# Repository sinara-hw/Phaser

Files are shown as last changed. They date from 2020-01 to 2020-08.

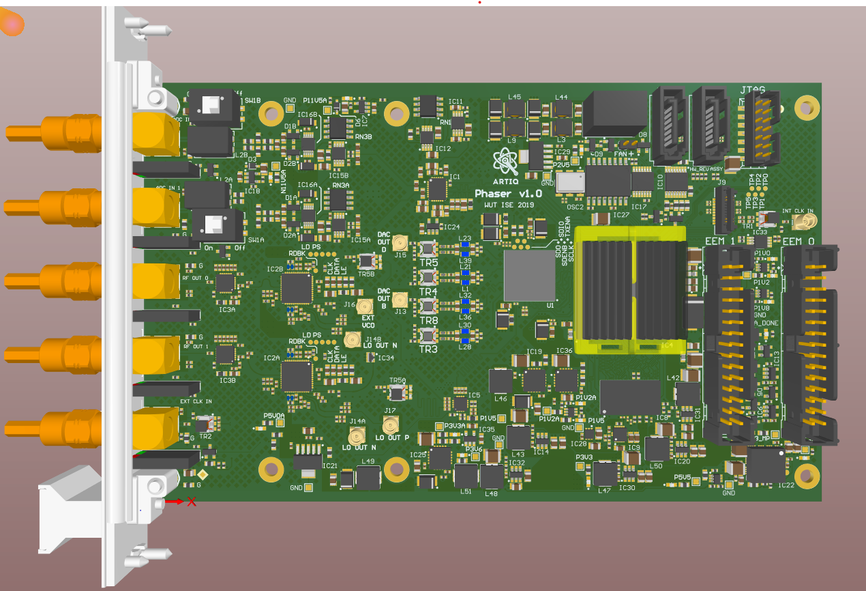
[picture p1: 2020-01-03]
DOC/Phaser-top.png

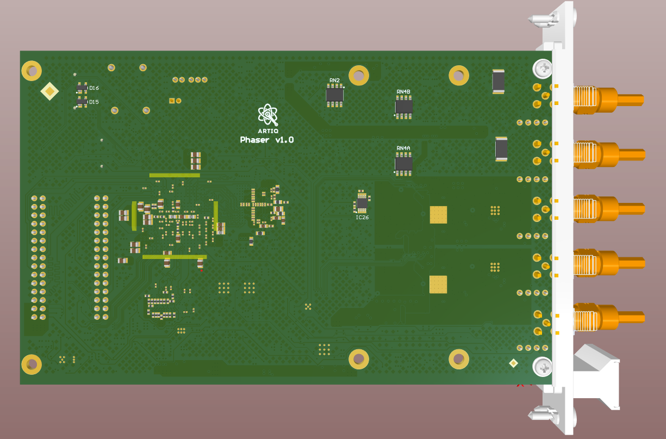
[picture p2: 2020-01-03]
DOC/Phaser-bot.png

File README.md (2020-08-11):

# Phaser
Quad channel 1GS/s RF generator card with dual IQ upconverter and dual 5MS/s ADC and FPGA in EEM form factor

## Design Files

Design files (schematics, PCB layouts, BOMs) can be found at [Phaser/Releases](https://github.com/sinara-hw/Phaser/releases).

## Wiki

More information can be found on the [wiki](https://github.com/sinara-hw/Phaser/wiki).

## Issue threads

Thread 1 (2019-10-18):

design sketch

hartytp, 2019-10-18:
2 channel ADC + DAC board

Hardware design sketch, needs fleshing out...

Digital:
- 2 EEM connectors
- TBD FPGA (probably small/medium Artix 7)
- Same RAM as Kasli
- Maybe a SATA or two
- Possibly, but probably not, Si5324 for DRTIO (would need to check power budget carefully to make sure this feasible)

Analog Input:
- Same as Sampler except
- Go for the 5MSPS ADC in the same family
- Increase AFE pole frequencies to ~1MHz to give more bandwidth

DAC:
- TBD DACs
- Two AFE population variants

Baseband AFE:
- Only using DAC I output, Ignore (terminate?) DAC Q outputs
- same AFE as Urukul
- Probably drop the pre-amps to keep the power dissipation down (in any case, with Booster we have gain to spare)
- Optionally drop the switches too

Upconversion AFE:
- ADL5375 IQ mixer (I and Q channels)
- same AFE as baseband mode, but different (no?) filter and magnetics

Clocking:
- 125MHz from SMA/MMCX/on-board XO
- HMC830 DAC clock PLL (copy loop filter from Sayma)
- HMC830 LO clock PLL (copy loop filter from Sayma)
- Decent LVDS clock fanout buffer

gkasprow, 2019-10-19:
Will we use 2x LTC2000 DAC then mixer and a single output?
Or two dual DACs and two mixers?

What about making the design 3-channel. Two baseband channels and one with upconversion? In this way switching from one mode to another won't require that many changes.

gkasprow, 2019-10-19:
do you want USB JTAG or we can use solution from Banker that Kasli can upgrade config FLASH via I2C ?

hartytp, 2019-10-19:
>Will we use 2x LTC2000 DAC then mixer and a single output?

The DAC will most likely be http://www.ti.com/lit/ds/symlink/dac34sh84.pdf

This has two IQ pairs. So, the idea is we either use only the Is and drop the Qs (baseband) or use an external IQ mixer depending on the desired output frequency range.

> What about making the design 3-channel. Two baseband channels and one with upconversion? In this way switching from one mode to another won't require that many changes.

We can't make three channels work in terms of thermal/power management, (front panel) space, EEM link bandwidth.

The proposal would be to just have a population option to select (basically, just a solder jumper to bypass the mixer). If that turns out to be hard to do, we can scrap the upconversion *the key element of this design is baseband performance, upconversion is an optional extra*.

hartytp, 2019-10-19:
> do you want USB JTAG or we can use solution from Banker that Kasli can upgrade config FLASH via I2C ?

I'll leave all those kinds of decisions to @jordens

jordens, 2019-10-20:
Some more background info on the design, DAC choice evaluation, DSP requirements etc:
https://paper.dropbox.com/doc/Phaser--AnD485kbUiDhEmmZ0cv8NUlZAg-yC4c4GTJ4hbA969VxIL9K

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

@gkasprow A way to talk to the flash via I2C would be really nice. But on Banker/Humpback this is really slow (a bitstream flashing operation takes some 5-10 minutes) and I think the I2C-SPI converter is the bottleneck (the way it limits and buffers each transaction). Maybe there is a simple way to speed it up or maybe we can figure out a different way to get this done over I2C.

@hartytp Didn't we say we'd use the DAC PLL to go from 125 MHz to 1 GHz DAC CLK? I didn't factor in the need to set up a HMC830 to clock the DAC.

hartytp, 2019-10-20:
> Also I'm not sure the Si5324 would be strictly needed for DRTIO. For the downlink it's not needed and for the uplink it may well not be required. And if there's a clock from MMCX/SMA then it's not needed for that either. I'd really try to minimize the clocking complexity for this.

Agreed, I don't want an Si5324.

hartytp, 2019-10-20:
> @hartytp Didn't we say we'd use the DAC PLL to go from 125 MHz to 1 GHz DAC CLK? I didn't factor in the need to set up a HMC830 to clock the DAC.

True, I'd forgotten about the internal DAC clock PLL. At one point we definitely discussed having 2 HMC830s, but it's very possible we agreed to scrap one later on and I forgot. Since we can steal the register set for the HMC830 from Sayma, I assume the additional work required to support a HMC830 for the DAC clock is basically just the usual work associated with hooking up an extra SPI bus?

In any case: (a) for the initial contract, the internal DAC PLL is definitely fine (b) I agree that we should try to minimise complexity/power consumption/cost as far as possible and should try to avoid using an HMC830 for the DAC clock (in any case, that's typically ~10-20dB less important than the mixer LO due to the frequency difference).

The things I would potentially be worried about with the internal DAC PLL would be noise and phase determinism (e.g. due to VCO auto cal). The latter may be solvable by using an active loop filter, fiddling with registers. I'll have a look at the data sheets/noise models and have a think. I'll open a separate issue on this.

jordens, 2019-10-20:
Iirc the DAC pll doesn't do any auto calibration. We'd set the vco range and be done. And I don't see how that would be affected by an active LF.
The DAC setup is pretty simple. We could freeze that and wouldn't have to implement some passthrough mechanism. The hmc830 does complicate things. it's pretty different.

jordens, 2019-10-20:
And the DAC34**H**84 would be sufficient. No S needed.

hartytp, 2019-10-20:
> Iirc the DAC pll doesn't do any auto calibration.

It may not; I haven't looked at the data sheet yet (just listing things that could be issues). AFAICT it's generally only the really high-performance ones that narrow-band step-tuned VCOs.

> And I don't see how that would be affected by an active LF.

Well, the question is why a step-tuned VCO would affect the output phase at all but empirically, it does! My understanding is that (a) the different bands on the same VCO can alter the leakage (b) the different bands change the DC bias voltage required to achieve a given output frequency, which (due to finite DC LF gain) requires a different DC offset at the phase detector. Putting an integrator between the PFD and VCO basically eliminates both effects.

The other thing I might worry about would be the PFD frequency for the DAC internal PLL (again, affects noise and drift). The 830 is nice as it can run directly at 125MHz. If there were any limitations that required us to run the DAC PFD at lower frequencies then I might be worried. but, again, this isn't something I've thought about yet, just a note to self for things to consider before finalising the design.

gkasprow, 2019-10-20:
Here is a very initial sketch. Just to estimate IO resources, power, clocking, etc.
[Phaser_SCH.PDF](https://github.com/sinara-hw/Phaser/files/3748520/Phaser_SCH.PDF)

jordens, 2019-10-21:
@hartytp Leakage and finite DC gain are the same thing in the loop filter. If there is no leakage, the DC gain is infinite and vice versa.
There is just one VCO and we need to do the coarse tuning (band select) ourselves in any case. The DAC provides a measurement of the LF voltage for that.
But sure, you can kill that effect with another integrator. I would suspect though that if PVT are sufficiently unstable to require an active LF to kill leakage-induced phase noise, you will typically also run out of the VCO fine tuning range because of PVT. And then the active LF is pointless.

jordens, 2019-10-21:
For IQ mixer, also check the [TRF3705](http://www.ti.com/lit/ds/symlink/trf3705.pdf). Better linearity, more output power, less noise, lower low-f corner, less bias, lower input power, more gain, but more power consumption, and lower high-f corner.

hartytp, 2019-10-24:
@gkasprow I looked over the design sketch. Looks good! I think the issues we've opened cover the main things. This time, let's try to finish the schematic review before doing work on the layout to avoid wasting time.

I'd like to send Stabilizer and Fastino to manufacture before beginning work on this in earnest. But maybe we can get to that some time next week? Depends on @jordens review timeline.

jordens, 2019-10-25:
I have already reviewed fastino and stabilizer as much as I'm involved. I'm not blocking those.
On phaser I can do some review next week. Between the issues and notes already filed and the design sketch there isn't much to be done.
Fpga wise an artix in that large pin compatible range from the a50t downwards will be fine (same as on sayma rtm).

hartytp, 2019-11-01:
@gkasprow I'm really keen to complete my initial design review soon. Could you have a go at producing a schematic only (no layout) RC please?

hartytp, 2019-11-05:
@gkasprow ping...what do you think the timeline for getting a schematic RC is? I'm itching to get this one off to manufacture and into my lab :)

gkasprow, 2019-11-06:
I plan to finish them until Friday.

hartytp, 2019-11-06:
🎆

Closed 2019-11-06.

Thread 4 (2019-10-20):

DAC LPF

gkasprow, 2019-10-20:
I assume we need some LPF filter between DAC and the mixer. The LPF needs to be fully differential. We can go for this [one](https://www.minicircuits.com/WebStore/dashboard.html?model=DLFCG-540%2B), but there are not many options with different frequencies.

jordens, 2019-10-21:
Or just a discrete one, like for the AD9148. Maybe not even such an aggressive 5th order. Yes, needs to be differential.
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

hartytp, 2019-10-21:
@gkasprow the MCL filter isn't the right approach IMHO. It only comes in a small range of values, none of which are what we'd ideally want (with 1GHz clock and 540MHz, you don't get much filtering for some of the lower frequencies we'll use).

I suspect that a well-designed discrete filter with tight-tolerance components will be the way to go

hartytp, 2019-10-21:
@gkasprow how important is it to use a differential filter instead of, say, two single-ended filters?

gkasprow, 2019-10-21:
The differential filter has usually better matching between negative and positive terminals. Moreover, depending on the construction, it may attenuate mainly differential components while two filters will attenuate both diff and common-mode components. Some differential filters are two single-ended ones in one package. So there is no simple answer to the question.
I don't think it is that important in our case.

hartytp, 2019-10-21:
@gkasprow do you know of any other sources of any other manufacturers of SMT RF differential filters. I didn't see any at a look (but I might have missed one).

For the upconversion, I guess we'd really want a double differential filter for the I and Q channels to maintain amplitude and phase balance. So, it's not so clear to me that 4xsingle-ended is really worse than 2xdifferential.

Unless you're worried about this, I suggest we just go for standard MCL single-ended filters. I'd expect that the matching between filters will be better than the matching between discrete filters.

gkasprow, 2019-10-21:
I'm not sure if lTCC would have tighter tolerance than a classical filter composed of 1% LC components.
They don't even specify the tolerance in DS.

hartytp, 2019-10-21:
Ok. Are you happy designing a discrete differential LPF for this then? Since it needs to work to 1GHz, we'll have to be careful to simulate the parasitics correctly to get something that performs as expected.

jordens, 2019-10-22:
I would also go for discrete. Third or fifth order like in the data-sheets and eval boards.

gkasprow, 2019-10-23:
I will simply copy the eval board layout.

gkasprow, 2019-11-06:
I plan to use this filter
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

hartytp, 2019-11-06:
Cool!

Questions:
- the dac/modulator there aren’t the ones we’re using. Does that matter (different parasitics)
- will you use the same BOM lines as the eval board to keep the parasitic the same?
- how much will the layout affect the response?
- do you have a curve of the filter response? If not, can we do a quick sim with all component models
- are you using components with very tight tolerances (eg the i and q channels need really good matching to preserver the mixers excellent side and suppression)

gkasprow, 2019-11-06:
I'm using 2% inductors and capacitors in the 0603 packages to make modifications easier. I will remove the lower layers of PCB to limit the parasitics. We are talking about 2 components 68nH and 2.7pF. In the case of the capacitor, the influence of its parasitic capacitance is critical and I'm not sure if we can precisely simulate such a circuit. EVKIT does not have any filter.
The DACs have current outputs that are loaded with 50R. It's hard to say if its parasitics matter that much.

gkasprow, 2019-11-06:
Anyway, I will estimate pads capacitances and do the simulation.

gkasprow, 2019-11-07:
The very first approach
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
and the charasteristics:
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

gkasprow, 2019-11-07:
This schematic includes all parasitic components
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

jordens, 2019-11-07:
ok. @hartytp I think this is probably worse than 0.1 dB flatness over 20 MHz already at 300 MHz.

hartytp, 2019-11-07:
> ok. @hartytp I think this is probably worse than 0.1 dB flatness over 20 MHz already at 300 MHz.

Indeed. 0.1dB is better than we need (just 1dB is a bit on the high side, but nought-dot-a-few-dB is ok).

hartytp, 2019-11-07:
Thanks greg, that looks pretty good. What are the inductor part numbers?

gkasprow, 2019-11-07:
Coilcraft 0603HP-68NXGLU

Closed 2019-11-07.

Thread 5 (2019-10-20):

Mixer bypass

gkasprow, 2019-10-20:
do we need a switchable mixer bypass?

hartytp, 2019-10-21:
No. Far too much effort to put in RF switches. Let's just make it a population option.

jordens, 2019-10-21:
Yes. Just 0R/capacitor jumpers.
It might make sense to maintain the baseband (no mixer) configuration as a different variant since the difference in population (PLL, fanouts, mixers, filters, biasing, new power rails etc) and cost is probably significant.

hartytp, 2019-10-21:
> It might make sense to maintain the baseband (no mixer) configuration as a different variant since the difference in population (PLL, fanouts, mixers, filters, biasing, new power rails etc) and cost is probably significant.

Yes, definitely.

Ideally, I'd also like a FP indicator (text/LED/whatever) to show which population variant one is using.

dtcallcock, 2019-10-28:
Bit late to the Phaser party, but anyway I'm very interested in using it for a new project.  However, I will need to be able to run down as low as 1MHz on the mixer bypass variant.  Is there a low frequency cutoff in the spec anywhere (I couldn't find one)?  If not, can we make 1MHz the spec?

The only issue I see right now is that the 10nF DC-blocks are a bit weedy.  Perhaps they could be 100nF in this variant?

jordens, 2019-10-28:
The balun (TLT vs not) will be the bigger hurdle for low f.

jordens, 2019-10-28:
Well, depends on how we do it. Whether the balun would bypass the mixer and whether the mixer is  unbalanced.

dtcallcock, 2019-10-28:
Yes, it seems that if this is a population variant there is quite a bit of flexibility.  I think I need to see a sketch of where we are right now though as I'm having a hard time picturing it from the comment threads.

hartytp, 2019-10-28:
@dtcallcock that should be possible. The magnetics are the things that are most likely to cause a problem. But I suspect we can find a way of making this work.

gkasprow, 2019-10-28:
@dtcallcock  I assume you want a circuit like in Urukul. We can make the balun assembly option so you could use one that works from 400kHz like [ADT1-1WT+](https://ww2.minicircuits.com/pdfs/ADT1-1WT.pdf). Anyway, this one works up to 800MHz so it should satisfy other applications as well.

hartytp, 2019-10-28:
Yes maybe that for the bb variant and a broadband tlt for the upconverter?

dtcallcock, 2019-10-28:
That works.

jordens, 2019-10-29:
We may get around having to use a transformer for.the upconverter variant.

hartytp, 2019-10-29:
How?

jordens, 2019-10-29:
There's no need for a transformer between mixer and upconv if the bias and matching work out (see data-sheets). And after the mixer it's already single ended.

jordens, 2019-10-29:
But for this application I am pretty sure that mixing down after phaser is actually the easiest approach. Then you can go all the way to DC.

gkasprow, 2019-10-29:
@jordens do you mean to use mixer as a diff to single ended converter with LO switched off ?

jordens, 2019-10-29:
I believe we'd use

* Baseband variant: dac, diff discrete lowpass, balun, digital attenuator, switch. The the balun could be the standard ADT 1-1 or maybe a 4:1 for a bit more power if that works with the matching
* Upconverter variant: dac, diff discrete lowpass, mixer, digital attenuator, switch.

jordens, 2019-10-29:
But yes. If you want to go all the way to DC, I'd use the baseband variant, and slap an external downconverter (125 MHz LO e.g.) after it.

hartytp, 2019-10-29:
@jordens yes, thank you, I'd forgotten that trf372017 has differential I/Q inputs, but single-ended RF output. So, we shouldn't need any balun for the upconversion path, which simplifies things. FWIW since the upconverter has internal DACs for bias control, I'd just AC-couple the DAC outputs in all cases.

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

hartytp, 2019-10-29:
(as you say though, we need to check that matching doesn't require a balun, so need to check data sheets/eval boards before making a decision)

hartytp, 2019-10-29:
> I believe we'd use

Yes, completely agree. We can potentially scrap the switch as well to get some more output power/reduce complexity, but I'm fine keeping it...

NB if we use the DAC amplitude rather than the switch to turn the output on/off then we'll need to rethink the noise eater control logic...

hartytp, 2019-10-29:
> But yes. If you want to go all the way to DC, I'd use the baseband variant, and slap an external downconverter (e.g. 125 MHz LO, Phaser into RF and use IF output) after it. It's not the ultimate solution in terms of low frequency noise but then again for DC applications other issues (like DAC tempco 15-30 ppm/K) might be problematic anyway.

I currently don't see any use-case for DC on this design. Without knowing the use-case, it's hard to comment on suitability, but I generally suspect this is not going to be the right design for dc-sensitive applications. e.g. may be better to use a bias-T to combine Fastino and Phaser outputs or something like that. Anyway, this is outside the scope of this design and a little off-topic.

jordens, 2019-10-29:
Yes. Let's kill the switch as well. If 40ns resolution is fine, then a virtual "TTL" channel to blank the output would be easy.

hartytp, 2019-10-29:
> Yes. Let's kill the switch as well. If 40ns resolution is fine, then a virtual "TTL" channel to blank the output would be easy.

I only imagine using phaser in cases where we need pulse-shaping, so the switch wouldn't be used anywhere in our setup (well, maybe to kill LO leakage during long off periods, but that's a bit niche).

Not sure what the right way of blanking the noise eater is. Maybe we just need to manually enable/disable it at the start/end of each pulse, but that's a separate conversation.

jordens, 2019-10-29:
Or we can just use the TXENA pin which presumably has either data clock resolution (2ns) or dac clock resolution (1ns). This is would be good for noise eating as well.
Unfortunately it affects both channels.

hartytp, 2019-10-29:
> Or we can just use the TXENA pin which presumably has either data clock resolution (2ns) or dac clock resolution (1ns). This is would be good for noise eating as well.
Unfortunately it affects both channels.

Well, worth hooking up the FPGA at least for future use.

jordens, 2019-10-30:
For silencing the output (LO leakage) there's also PWD_TX_DIV in the upconverter accessible through SPI and AFAICT without sideeffects.

gkasprow, 2019-11-06:
I got the mixer devkit. If som measurements are needed, I can make them.

gkasprow, 2019-11-06:
I left the RF switches.

hartytp, 2019-11-07:
Where are they? I don’t think we can have a switch on the I as it will destroy the I/Q matching. Let’s just use solder jumpers

jordens, 2019-11-07:
I think he meant the RF switch after the mixer.

hartytp, 2019-11-07:
@gkasprow either way, let's drop it. Unnecessary insertion loss and complexity and we can quickly turn the DAC off in software so it's not helpful to have a separate switch

gkasprow, 2019-11-07:
I meant this circuit
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
OK, let's get rid of them.

Closed 2019-11-07.

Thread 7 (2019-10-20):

Config FLASH update

gkasprow, 2019-10-20:
> A way to talk to the flash via I2C would be really nice. But on Banker/Humpback this is really slow (a bitstream flashing operation takes some 5-10 minutes) and I think the I2C-SPI converter is the bottleneck (the way it limits and buffers each transaction). Maybe there is a simple way to speed it up or maybe we can figure out a different way to get this done over I2C.

What about making SPI FLASH available on the LVDS lines?
One can achieve it in a few ways:
- add LVDS mux that switches 4 EEM lanes to the FLASH. It is controlled by I2C. Simplest and robust. LVDS muxes like [this ](https://www.maximintegrated.com/en/products/analog/analog-switches-multiplexers/MAX14979E.html) They do not cause additional lane delays.
- make the FLASH inerface inside of the FPGA as it is done for JTAG FLASH programmer. Needs some gateware development and is not fail-safe. One cannot recover in case of broken flash content
- use existing I2C to SPI converter + add  tihgtly coupled, slow LVDS receivers that work only for FLASH writing. I2C to SPI works for status/readout. In this way we avoid switching the LVDS bus but it may cause issues and complicates the things since require both I2C and SPI access.
- make a CPLD  I2C to SPI bridge that utilises fast I2C mode.

jordens, 2019-10-21:
(1) is pretty complex on the coding side and would need quite some development on Kasli and then it's as easy to do (2) instead which doesn't need additional hardware. (3) also requires additional tooling, gateware and scatters some complexity across different interfaces. My impression is that (4) would also require quite some development work for not that much gain and reusability.

I would keep the existing I2C-SPI solution and go for (2) at some later point.
There are good ways to make it (almost completely) fail-safe with multiple bitstreams in flash and warm booting.
And we already have two decent, robust solutions (JTAG cable and I2C-SPI). If we can't implement (2) then they are good enough for me. Waiting 10 minutes for a firmware update is not that dramatic at the user end. Developing with JTAG connected is a must in any case since flashing is still about 2 orders of magnitude slower than loading a bitstream via JTAG. No point in wiring up another FTDI solution here.

gkasprow, 2019-11-06:
done.
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

jordens, 2019-11-07:
Is the FPGA's CFG_CCLK high-Z during INIT_B low? I'm not sure since it's dedicated.

jordens, 2019-11-07:
I believe the answer to the above is yes.

But wouldn't it be useful to connect PROGRAM_B to a I2C-SPI GPIO (and either derive FLASH_UP_EN from INIT_B or to drop the FPGA_DONE input)? INIT_B alone doesn't reload the configuration.

gkasprow, 2019-11-07:
Right. Do we need INIT_B at all?

gkasprow, 2019-11-07:
OK, to hold FPGA configuration one needs to hold init_B low. TO restart configuration one needs to toggle PROGRAM_B. So, what if I connect them both with two Schottky diodes to GPIO?
In this way I will pull them low together.
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

jordens, 2019-11-07:
Schottky sounds good. Just make sure that they can pull low enough against the pullups.

gkasprow, 2019-11-07:
DONE line has 300R pullup so I will add two MOSFETs.
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

Closed 2019-11-07.

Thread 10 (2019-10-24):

choice of upconverter

hartytp, 2019-10-24:
I'd like to aim to use upconverters with inbuilt LO PLLs. The thinking here is that it's highly desirable to have a LO PLL on the EEM, rather than relying on an external LO. Generating the LO with a PLL outside the modulator is mildly tricky because the quadrature hybrids in the upconverter don't like harmonics, which most PLLs produce. Filtering the harmonics is a pain. Easier to let the modulator designer take care of that. Having the PLL inside the LO also makes the two channels fully independent, which may or may not be useful for a given application, and means we only have one clock frequency to distribute (the reference)/saves us a front panel connector.

The potential downsides of using a modulator with inbuild PLL/VCO are:
- power consumption -- but, doing the maths, I don't think having two PLLs/VCOs uses much more power than having an external PLL (at least, for a high-performance one like an HMC830)
- less choice of modulator.

@gkasprow do you know any manufacturers of upconverters with PLLs/VCOs apart from TI and ADI? I'll post a table here with our options soon.

hartytp, 2019-10-24:
PN | BW (GHz) | power (W) | supplier |
---| ---| --- | --- |
[trf372017](http://www.ti.com/lit/ds/symlink/trf372017.pdf) | 0.3-4.8 | ? | TI
[trf3722](http://www.ti.com/lit/ds/symlink/trf3722.pdf) | 0.4 - 4.2 | ? | TI

hartytp, 2019-10-24:
*TRF372017*
- internal bias
- VCO output, route to MMCM/UFL for debugging (can be DNP by default)
- 200mA from 3V3, 117mA from 5V = 1.245W
- f_pfd max: 100MHz (so we will run at 62.5MHz)

VCO at 2GHz, noise normalised to 1GHz

f offset | HMC830 noise (-dBc/Hz) | trf372017 noise(-dBc/Hz)
--- | --- | ---
10k | - | 92
100k | 122 | -
1M | 147 | 139
10M | 168 | 157
50M | 177 | 160

So the VCO is something like 10dB worse than the HMC830, which is fine.

- PLL figure of merit is the normalized phas enoise floor of the PFD in dBc/Hz. i.e. measure in-band phase noise (closed loop) and subtract `20log(N) + 10log(f_pfd)`
- HMC830 is (integer-N) is -230dBc/Hz. So, at 2GHz, f_pfd=62.5MHz that gives
  - N = 32
  - `PN = -230dBc/Hz + 20*log(32) + 10*log(62.5) = -122dBc/Hz`
- For TRF372017 (figure 21)
  - `f_pfd` = 1.6MHz, `f_lo_out = 1GHz` so `N = 625`
  - `FOM = -103 - 20*log(625) - 10*log(1.6e6) = -221`
- So, again, the TRF372017 PFD is about 10dB worse (I can't find a flicker spec for this PN)
- Bearing in mind that the 830 is about the best on the market for PLL with integrated VCO, that's good!

hartytp, 2019-10-24:
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

Worse case variations are of order 0.2dB/60K = 0.07%/K. From the plots, it's generally quite a bit better than that (a lot at certain frequency/temp combinations)

hartytp, 2019-10-24:
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

hartytp, 2019-10-24:
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

hartytp, 2019-10-24:
trf3722
- seems broadly comparable.
- VCO bb noise is a bit better, close in noise a bit worse. PFD FOM is about identical (-221dBc/Hz)

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

hartytp, 2019-10-24:
HMC1197
- 320mA*5V + 48mA*3.3V = 1.75W
- PFD FOM is -230dBc (integer N)
- VCO is pretty close to HMC830

- NB I assume the TI FOMs were integer N, but wasn't specified in data sheet, could have been fractional-N (but I doubt it)...

hartytp, 2019-10-24:
My feeling is that we should go for the trf372017. Covers a good frequency range. Not too power hungry. Decent noise. Well specified, nice internal biasing.

@gkasprow @jordens any objections/other suggestions, or shall we freeze that choice.

jordens, 2019-10-25:
The advantage of a shared pll would be differential phase if we don't use integer n.
Other than that the trf372017 is good.

hartytp, 2019-10-25:
Okay, if it’s not hard to route, let’s hook ch0 LO our to ch1 LO in. Then ch1 LO our to mmcx. That provides an option for this

gkasprow, 2019-10-25:
@hartytp did you look at Maxim ? They have quite a few up/downconverts but I'm not sure if they work above 3GHz.
Other vendors
Quorvo
NXP
Macom
IDT

Interesting ICs
https://pl.mouser.com/datasheet/2/412/ffc5071_5072_data_sheet-1506879.pdf
https://pl.mouser.com/datasheet/2/412/f2054_data_sheet-1110962.pdf

hartytp, 2019-10-25:
Thanks @gkasprow! I'll have a look at a few of those before Monday. Although, I'm already quite happy with the trf372017, so I'll need to find a good reason to switch.

hartytp, 2019-10-25:
From Quorvo, the possible choices are https://www.qorvo.com/products/frequency-converters/integrated-synthesizers-with-mixers#ta0050;;aa0112:2,aa0112:2;/

They are generally quite nice (I've never seen a chip like that with an active LF before).

However, the thing I don't like about them is the mixers. They're not IQ mixers, which is inconvenient as we'd have to externally filter the unwanted sideband. And, the input/output coupling requirements for the mixers look more annoying than the TI chips.

So, nice chips, but I don't see a significant win over the TI offerings.

hartytp, 2019-10-25:
I don't see any Macom upconverters with integrated LOs, so let's rule them out.

hartytp, 2019-10-25:
Also, AFAICT, the Quorvo chips have to be bought directly from the manufacturer which, I imagine, is annoying for the assembly house https://octopart.com/search?q=ffc5071&sort=median_price_1000&sort-dir=asc

Do you know of any reason we'd prefer those to the more readily available TI offering?

hartytp, 2019-10-25:
I don't see any directly comparable NXP products.

hartytp, 2019-10-25:
I don't see any IDT parts in a comparable frequency range, so that rules them out too (unless I'm missing something -- the way these companies sort the parts always confuses me!).

So, thanks a lot for the links @gkasprow but AFAICT the trf372017 is still the best option.

Unless anyone has anything else to add, let's fix that design choice.

That's the component identification / circuit topology phase complete! Next stage is schematic review. Whoo!

hartytp, 2019-10-25:
The RFFC5071A VCO/PLL noise seems worse than the TI part.

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

FOM: Phase noise is around -100dBc/Hz with 26MHz REF and 1.5GHz output. N = `FOM = -100dBc/Hz - 20*log10(58) - 10*log10(26e6) = -210dBc/Hz`

hartytp, 2019-10-25:
Power consumption is only 330mW or so, which is a lot lower than the other modulators. But I think that's mainly because it's not a proper IQ modulator.

Let's go with the TI chip

gkasprow, 2019-10-25:
That's fine with me. You asked about another options so you got them :)

hartytp, 2019-10-25:
Indeed, thanks for the links - always good to see more options

gkasprow, 2019-10-28:
@hartytp one remark. Correct me if I'm wrong, but we decided to use PLL + mixer combo because external PLL like HMC830 delivers square waves and requires filters. But this combo chip does exactly the same. You will still get plenty of harmonics without the output filters. I didn't notice any filters on the block shematic of the ICs. Such filters would need to be bulky and tunable in wide range.

hartytp, 2019-10-28:
@gkasprow thats a good question and one I was thinking about too. Short answer is that the ic designers take responsibility for this issue and how to solve it. The ic performance is well specified so clearly they have some solution. Not sure how they do it!

gkasprow, 2019-10-28:
Are you sure they specify the IC for operation with such wide bandwidth? These chips are usually used for relatively narrowband circuits. I'd buy devkits of these ICs give it a try. This looks too good to be true:)

hartytp, 2019-10-28:
The spec is pretty clear afaict. Have a look and see what I’m missing. I can buy a dev kit and do some tests, but I’m not sure what I’d be looking for. Conversion gain variations? Sb suppression?

jordens, 2019-10-28:
I can imagine that with an integrated vco the quadrature generation can be done in a different way than with the 90 deg hybrid.

gkasprow, 2019-10-28:
@hartytp correct me if I'm wrong.  You want to shift the entire IQ bandwidth of -300 ..+300MHz up to let's say 3.2GHz +/- 300MHz. With such upconverter IC you will get also products at 9.6GHz +/- 300MHz which can be easily filtered away. So no issue here.
But if somebody wants to convert it to let's say 1GHz +/-300MHz, the products will be also at 3GHz and 5GHz.  THat's the only thing I'm worried about. I have an impression the DS does treat it as an obvious thing. ADI has also a [note ](https://www.google.com/url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)about such switching mixers.

hartytp, 2019-10-28:
@gkasprow right. There are two separate issues here:
- for a standard IQ upconverter, harmonics on the LO mess up the LO quadrature hybrid and can seriously impact performance. For this reason, the typical recommendation is the 3rd harmonic to be something like -30dBc, which is tough when using an external wideband step-tuned PLL
- beyond that, there will doubtless also be low-level output spurs at harmonics of the LO. That's the case even with a standard passive mixer. Again IIRC, it's well specified on the IC data sheet. This may or may not be an issue depending on the use-case. Since we have no pre-amp and won't operate any part near saturation, it's easy for the user to filter these off later on (e.g. with an MCL SMA LPF). This is something I'd think of as a standard RF issue that people need to be aware of.

gkasprow, 2019-10-28:
That's true.  Without the wideband hybrid, we get only 3rd and 5th harmonics which are easy to remove.
Anyway, I will buy the devkit to have the GUI and interface to quickly characterise the Phaser board once it's ready, without waiting for ARTIQ support.

hartytp, 2019-10-28:
Exactly.

Sounds like a good plan.

Now all critical components are selected, what do you think the turn around time for this project is likely to be?

gkasprow, 2019-10-28:
well, it depends on priorities,  Phaser or Pounder can wait ?

hartytp, 2019-10-28:
From my end, Phaser is by far the top priority. Others may feel differently ;)

hartytp, 2019-10-28:
I have time to do design reviews right now, so I can promise to turn things around quickly :)

gkasprow, 2019-10-28:
I have other high priority design to finish. I plan to do it by Wednesday. Then we have holidays so will be away. I will work on it next week. Anyway, the end of next week (Nov 10) seems to be feasible, I will do my best to publish the files for review earlier.

hartytp, 2019-10-28:
That would be awesome! Although if time is tight, finishing booster remains my number 1 priority over all

dtcallcock, 2019-10-28:
> Phaser or Pounder can wait ?

I'm happy for Pounder to move down the queue for Phaser.

Closed 2019-11-06.

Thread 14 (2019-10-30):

mixer sideband suppression and carrier nulling

jordens, 2019-10-30:
The strategy to do this should be thought through now. This will be frequency/power/temperature dependent and will need to be done by the user.

Anything simpler than downconverting (LO amplifier + mixer + lowpass) one channel using the other channel and using the on-board ADC? Write software to do this, maybe map that and add to coredevice driver.
Or do we want to on-board this so it can be done without the required 12 SMA disconnect/reconnect cycles?

hartytp, 2019-10-30:
Thanks @jordens. This is something I've considered but not written up yet.

The uncompensated sideband and carrier suppression is

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

So, the first question is whether the applications we have in mind for this design need anything better than those unadjusted numbers.

I'd be interested in input from other users -- so far the input I've had has been "we don't need upconversion -- but speaking for our work, the answer is that the unadjusted numbers are fine. These are two very specific spurs, whose location can be controlled to a certain extent by appropriate choice of LO, and those levels are fine for us.

As you note, the calibration is nasty as it's non-linear, frequency dependent, etc and the benefit for our work is too small to bother

hartytp, 2019-10-30:
I'd also be wary of adding extra hardware to phaser to cover this unless someone presents a strong use-case. I feel we're a bit marginal on power consumption already and I'm generally wary of complexity/cost for these designs.

hartytp, 2019-10-30:
The other thing I'd add is that it's likely that the PVT variations are quite a bit smaller than the dependence on the LO frequency. As such, for a given LO frequency, it's likely one can calibrate one channel of one board and then determine appropriate Vcm etc to use. That would be a per-use (per LO frequency) rather than per channel calibration, so the number of SMA connections/reconnection is less important.

gkasprow, 2019-10-30:
The power of the feedback circuit can be disabled entirely when not needed.

jordens, 2019-10-30:
I could imagine that when jumping around in a Forrest of hyperfine/Zeeman transitions the unwanted sideband and carrier might be problematic. It certainly depends on the application though.
With the external or internal setup your be able to map out the full frequency/Power space and tune balance and offset. That's how e.g. the gnuradio boards do it.
The internal one would need a coupler, (simple) mixer, and lowpass. We could use the lo outputs and cross the channels. Either with Rf switches and a single downconversion chain or duplicating the downconversion circuit.

jordens, 2019-10-30:
Still, to do the mapping with the external circuit it would be comparable to the connector juggling you have to do when calibrating a vna.

hartytp, 2019-10-30:
> I could imagine that when jumping around in a Forrest of hyperfine/Zeeman transitions the unwanted sideband and carrier might be problematic. It certainly depends on the application though.

Sure, I can imagine situations where it would be an issue. For the experiments I have in mind, I'm confident it won't, and I'm wary of designing for a use case I don't fully understand.

> With the external or internal setup your be able to map out the full frequency/Power space and tune balance and offset. That's how e.g. the gnuradio boards do it.
> The internal one would need a coupler, (simple) mixer, and lowpass. We could use the lo outputs and cross the channels. Either with Rf switches and a single downconversion chain or duplicating the downconversion circuit.

Ok. If you have a design in mind that's low cost/power/complexity and you think will expand the user-base for the design then I don't object to adding it (although, I don't think I'll be able to provide much input for the design or any additional funding).

jordens, 2019-10-31:
If there is no interest in doing this then we can close it. Investing in it is too risky for me.

hartytp, 2019-10-31:
Ok. As I said I can see the value for some use cases, but it wouldn’t be particularly helpful for us and I’m reluctant to design for something without a concrete use case.

We can always add this in a future design revision if it becomes important for someone

Closed 2019-10-31.

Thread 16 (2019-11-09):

ADC input: floating

jordens, 2019-11-09:
* shield should be floating (there is a 100k to ground later)
* ~center should be dc coupled~ (already implemented)

gkasprow, 2019-11-09:
OK, I didn't generate an assembly variant

jordens, 2019-11-09:
Also: I'm ok with dropping the switchable termination. Few people use it and it needs space. But I'd still like a DNP 50 R termination.

gkasprow, 2019-11-09:
added 49R9 0603.

hartytp, 2019-11-09:
Currently (at least in the baseband variant) the SMA is not floating as it should be.

Also, I'd prefer to keep the switchable termination unless there is a good reason to remove it

jordens, 2019-11-11:
#36

gkasprow, 2019-11-28:
done. Added switchable termination and LED indicators on the front panel.
Removed 0R that shorts SMA to GND  but kept 10nF

Closed 2019-11-28.

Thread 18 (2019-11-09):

FPGA selection/powering/banks

jordens, 2019-11-09:
* FPGA package is good
* don't use bank 13 (unavailable on 50t and lower)
* ~maybe don't power bank 13 if we don't need it~
* ~bank 16 signals could be moved to bank 14~ ~and bank 16 could be depowered~
* FPGA can be 50T for now (if that's cheaper and available)
* Speed grade can be -2 (1250 Mb/s serdes, 800 Mb/s DDR3 4:1)

jordens, 2019-11-09:
Leaving unused banks unpowered is apparently not recommended.

> 2) In the case of a completely unused I/O bank, leaving the VCCO pins of unused I/O banks floating reduces the level of ESD protection on these pins and the I/O pins in the bank and is generally not recommended. However, ESD events at the unconnected solder balls in the inner rows of the pin array are unlikely and not considered a high risk.
https://www.xilinx.com/support/answers/11906.html

gkasprow, 2019-11-09:
lack of bank13 complicates pin assignment and routing. Are you sure that 50T would be enough for any application?

hartytp, 2019-11-09:
My tuppence worth here is that fpgas are relatively cheap and I like to have room for expansion later. Particularly if it makes the routing easier

Having said that I’ll leave the final call to @jordens

jordens, 2019-11-09:
Can't you could use banks 14/15/16 for all the pins in 13/14/15/16 currently?

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

I would really like to keep the pin compatibility all the way down to 50T and lower. I'm pretty certain that 50T is fine for all applications envisioned currently.
But if you have good reasons (routing, availability, price) to go for 100T, then I'm easily convinced.

jordens, 2019-11-09:
The price difference is on the order 5-10% of the estimated board cost.

jordens, 2019-11-09:
I'm not insisting at all. Just pointing out that using bank 13 blocks using a cheaper FPGA. For the baseband application (no cost and power consumption for mixer/lo and their power supplies) that's very much noticeable. Just counting pin numbers and pin types I don't see a problem. But if you need more PCB layers because it complicates routing, then the price difference doesn't matter.
I'll probably have a number on resource consumption and gateware feasibility next week if I can get the netlist of the next RC.

gkasprow, 2019-11-09:
This means that EEM port would be splited between DAC bank (8 LVDS) and ADC bank (8 LVDS). If it is not an issue, then we can skip bank 13.
I'm a bit worried about using all pins in DAC bank due to SSO - it will be used at very high rate.

jordens, 2019-11-09:
Splitting the two EEMs between banks is fine with me as long as each EEM remains within a bank and the first LVDS pair of each EEM is on a MRCC. We plan to use one source synchronous clock on each EEM anyway.

Alternatively move the ADC LVDS stuff from bank14 into the DAC banks and use bank 14 for EEM.

Distributing the DACs evenly among banks 15 and 16 is also good. Let's try to keep it symmetric for debuggability: LVDSA and PARITYAB in one bank. And LVDSB and PARITYCD in the other bank. Distribute SYNC/DATA_CLK/ISTR/OSTR as you like among those two banks.

gkasprow, 2019-11-09:
OK, done.

jordens, 2019-11-09:
You have DATA_CLK in each bank 15 and 16. Was that intentional?

gkasprow, 2019-11-09:
I already fixed that.

Closed 2019-11-09.

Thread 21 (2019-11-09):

baluns

jordens, 2019-11-09:
TR5A/B can be the same as TR1 and TR4. Alternatively skip them and take a single ended output of the clock fanout.

TR2/3 can also be the same as TR1 and TR4 or can be dropped alltogether (as we do on Urukul).

gkasprow, 2019-11-09:
I placed a note that explains why I used TR5A/B baluns. The clock amplitude from a single output is barely enough.
TR2/3 will be DNP by default.
TR1 and 4 are big and occupy 4x the place SOT23

jordens, 2019-11-09:
ACK then this is perfect.

jordens, 2019-11-10:
IMO the four baseband baluns TR1/4/7/6 could be changed from [ADT1-1WT](https://www.minicircuits.com/pdfs/ADT1-1WT.pdf) for significantly smaller (~1/4 area) parts, like the [TC1-1T](https://www.minicircuits.com/pdfs/TC1-1T.pdf), at the cost of 0.3 dB more loss at 300 MHz, same low f corner, reduced high-f corner from 800 down to 500 MHz.
There are also even better pin compatible versions in the pipeline for the future like the [TC1-ED9236C/1](https://www.minicircuits.com/pdfs/TC1-ED9236C-1_SPEC.pdf).

dtcallcock, 2019-11-10:
Isn't the ADT1-1WT a 75Ohm part?  Was that intentional?

jordens, 2019-11-10:
Yes. That as well. But I don't think it matters in practice.

jordens, 2019-11-10:
It comes from the [AD9910 devkit](https://github.com/sinara-hw/sinara/issues/272#issuecomment-330066162) and is used on Urukul as it plays better in the second and third Nyquist zones.

jordens, 2019-11-13:
@hartytp @dtcallcock let's settle this and #60

I'd suggest
1. the baseband baluns to be 1:4 TC4-1Txx, with corresponding changes to the AA filter impedance for the baseband variant
2. the upconverter to have no balbals (amplitude seems right, fewer nonlinear/unmatched elements)
3. make the layout so that the upconverter could receive balbals: use the baseband balun footprint, add balbal bypass jumpers, and place the mixer bypass caps (for the baseband variant) after the balun.
4. consider using that same TC4-1Txx for TR5A/B (upconverter reference) for BOM reduction

hartytp, 2019-11-13:
I'm happy to defer to @gkasprow on this.

> make the layout so that the upconverter could receive balbals: use the baseband balun footprint, add balbal bypass jumpers, and place the mixer bypass caps (for the baseband variant) after the balun.

Okay, but I want to keep the layout tight there to minimize parasitics/potential mismatches between the I & Q channels. Surely the methodology here is to calculate the expected output power without the balun and compare that to what the modulator wants. If we don't need a balun then better to remove it.

I'm pretty sure we'll end up with a v1.1 release pretty quickly to fix bugs, so we can always add baluns later on.

gkasprow, 2019-11-14:
I added a path with baluns for upconverter version. but if we find it difficult to route, I will remove these components.

hartytp, 2019-11-18:
I think the conclusion was to do this: https://github.com/sinara-hw/Phaser/issues/21#issuecomment-553369958

gkasprow, 2019-11-20:
OK, what did I do wrong?

jordens, 2019-11-21:
See https://github.com/sinara-hw/Phaser/issues/65#issuecomment-555157136 and https://github.com/sinara-hw/Phaser/issues/21#issuecomment-553369958 (above)

# v1.0rc3

## Baseband

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

## Upconverter

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

TR3 should be usable **in place of** R59/R2:
1. Place TR3 (DNP in upconverter) in parallel to R59/R2 (DNP in baseband)
2. Move jumpers R3 and R17 (DNP in baseband) to between DACOUTA_P/N and TR3:1/3
3. Add jumpers (upconverter DNP) between TR3:1/3 and DAC_OUT0/GND
4. TR3 should be TC4-1T
5. Check whether that impedance ratio for baseband requires changing R11/R12/R1017/R37/R39 for that variant
6. Check whether TR3:2 or TR3:5 is the center tap and place that on the input (good for baseband)
7. Same for the other four DACs

CannaCardo, 2019-11-23:
1-4 done

gkasprow, 2019-11-29:
I can place both ADT1-1WT and TC4-1T+ as dual footprint solution.
Can we use TC4-1T for baseband?

gkasprow, 2019-11-29:
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

jordens, 2019-11-29:
Currently:

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

I'd go for TC4-1T for baseband and bypass for upconverter. No dual footprint needed. There hasn't been any objection to that IIRC.

jordens, 2019-11-29:
But don't forget about (6) for baseband and 1:4.

hartytp, 2019-11-29:
@gkasprow once this is fixed please can you upload a new schematic rc. Hopefully we can then sign off on the schematics.

gkasprow, 2019-11-29:
Yes, I plan to do it today.

Closed 2019-11-29.

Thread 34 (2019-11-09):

sma_clk sel

hartytp, 2019-11-09:
Is 2V5 but the clock buffer is running off 1V8. Is the idea here that the 470Ohm resistor current limits, making this ok? 0.4V across 470Ohm is less than 1mA, which sounds ok, but are you confident this won't cause any issues (particularly sequencing issues/lock up/etc)?

gkasprow, 2019-11-13:
The 1V8A wakes up together with P2V5 so I'm pretty sure it  would work.
Modern ICs require roughly 20mA or more to develop latchup.

Closed 2019-11-13.

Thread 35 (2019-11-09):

EMI filter

hartytp, 2019-11-09:
@gkasprow the  EMI filter annotations imply that the DM BW is greater than the CM BW. That's not normally what one wants because the (poorly matched) DM filter will kill the InAmp's CMR (https://www.analog.com/media/en/training-seminars/tutorials/MT-096.pdf). Shouldn't we significantly increase the CM filter BW?

If so, we should check on Stabilizer/Sampler/Thermostat

hartytp, 2019-11-09:
Or, is the point that the CMC is expected to provide such good CMR at these frequencies that we're not worried? If so, we should make that clear in the annotations

gkasprow, 2019-11-13:
the CM inductance is 6.5mH and with 8.2pF it makes 689kHz filter, of course, if we ignore parasitics.
The idea was to imoprove the opamp CMRR above 100kHz
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

hartytp, 2019-11-14:
> The idea was to imoprove the opamp CMRR above 100kHz

That's not the only thing I'm worried about. Suppose you don't have the choke, just an RC CM/DM filter. In that case, component matching tolerances in the CM filter will lead to CM->DM conversion. This tends to dominate the overall AC CMMR, not the InAmp. As a result, one needs to add a DM filter with a much lower BW to prevent this. Without the DM filter, the AC CMMR will be much much worse than the InAmp. The DM BW should ideally be an OOM below the CM BW for this to not be an issue.

The CMC helps the situation by removing common-mode noise. But, in that case, I think you still want the CMC filter BW to be an OOM below the RC filter CM BW.

hartytp, 2019-11-14:
NB the CM bandwidth quoted on stabilizer is the LC resonance for the input CMC filter

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

gkasprow, 2019-11-14:
That's correct. To do this, we would have to increase the 18pF capacitor and increase the 1k8 resistor to preserve the bandwidth. Let's simulate that.

gkasprow, 2019-11-14:
Here is the schematic
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
And Common mode response
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

After adding some asymmetry to the input filter - instead of 8.2p I used 10p. Indeed, the CM gets much worse, already at 1kHz

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

gkasprow, 2019-11-14:
With CMC and asymmetry, it does not help much.
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
Even when I increase the capacitances 10x ad reduces resistance 10x it does not help much

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

The assymetry plays essential role.
With 2x 8,2pF (symmetrical design) it works nice
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
and the same, symmetrical circuit without CMC

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
It does help for a higher frequency, providing that the design is symmetrical.
If we want to make use of it, we would have to add trimmer and calibrate it with CM signals.

gkasprow, 2019-11-14:
If sb wants to play, here is the Tina [simulation file](https://www.dropbox.com/s/ae131ovahxb59yw/ADC_AFE.TSC?dl=0)

hartytp, 2019-11-18:
Let's leave it as is for now. The CMMR is still pretty good

jordens, 2019-11-18:
Wouldn't it be sufficient to move the common mode high-z 100k termination to before the CMC and have only differential filters after the CMC? That 100k can also be 100k to GND on negative and 1M differential FWIW. Do we need common mode RC filtering at all after the CMC?

hartytp, 2019-11-18:
@jordens I don't follow you. How is the 100k termination relevant here?

How would having only differential filters help?

> That 100k can also be 100k to GND on negative and 1M differential FWIW

Do you mean replacing the 100k to ground on the signal input with a 1M differential termination? We can do that, but I don't see any particular advantage.

hartytp, 2019-11-18:
> Do we need common mode RC filtering at all after the CMC?

I'm not sure I follow this. We want the differential filter to avoid rectifying pickup. The CMC doesn't do any filtering into a high-Z load, so we need the CM capacitors for it to filter. Those constraints give you the topology we have.

jordens, 2019-11-19:
That doesn't match what I've see. The CMC does change the response a lot, also just before a high-z load. We measured this a while back. I assume this is because of the interaction with the cable and the source.
And if you want a differential filter to filter (differential) pickup then you don't need common mode capacitors. As you note that kills your common mode rejection.
And third, even if you want a common mode shunt, it's simply incorrect that you are constrained to the topology here. Just split the (large) differential capacitor and shunt that center tap with a smaller cap. For f_common > f_diff this should be less sensitive to component tolerances.

hartytp, 2019-11-19:
> That doesn't match what I've seen. The CMC does change the response a lot, also just before a high-z load. We measured this a while back. I assume this is because of the interaction with the cable and the source.

To clarify: when I say "high-Z" I mean "high-Z at the relevant frequency". i.e. an open-circuited 1m BNC cable isn't high-Z by the time you get much above DC because of the ~100pF capacitance.

If we accept the model that (within the CMC BW, which is high in our case) a CMC is a small differential-mode inductance and a large common-mode inductance, it can't do anything if the load is truly high-Z (by which, I mean that at the relevant frequency it's impedance is high compared with the CMC inductance).

The InAmp input capacitances are only ~10% of the capacitances used in the CM/DM filters we use. So, if we scrapped the CM filter capacitors, we'd move the CM filter pole up by an order of magnitude, which would significantly reduce the CM filtering.

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

When you say this doesn't match what you've seen, do you mean looking at Zotino's outputs on a scope? If so, the cable + scope capacitance stop being a high-Z load at relatively low frequencies.

hartytp, 2019-11-19:
> And if you want a differential filter to filter (differential) pickup then you don't need common mode capacitors. As you note that kills your common mode rejection.

No, that's not what I'm saying. The decreases common-mode rejection at AC comes from two places: the mismatch in the resistors, which are common to both the CM and DM filters, and the mismatch in the DM filter capacitors.

It's relatively cheap to use 0.1% resistors for the DM filter, but hard to get the capacitors better than 5%. As a result, the dominant source of DM->CM conversion is typically the capacitors. This is why the standard design for EMI filters (see the app note I linked above) has a CM filter with a cut-off below the DM filter; the extra CM filter mitigates the loss in CMMR caused by the DM filter. i.e. if you have a DM filter then the CM capacitor will improve the AC CMMR, not reduce it.

hartytp, 2019-11-19:
Nope, sorry, that's not a correct explanation. See here for a better explanation: https://www.analog.com/media/en/technical-documentation/application-notes/AN-671.pdf

The point is this:
- even with the CMC you still need a the two CM filter capacitors to prevent rectification of CM noise. If you don't use external capacitors then you're relying on the parasitic capacitances, which isn't really better
- you also want a DM filter to prevent rectification of DM noise
- the DM filter cut-off should generally be lower than the CM filter cut-off to make sure we catch CM->DM conversion from the CM filter

hartytp, 2019-11-19:
NB in the app note I linked to they do have a design with only a CMC:

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

However, as I understand it:
(a) This doesn't do any DM filtering, which I would like to
(b) it relyies on forming a filter between the parasitic (e.g. OpAmp input) capacitance and the CMC inductance. For the choice of CMC and InAmp we have, that filter cut-off would be a bit too high.

jordens, 2019-11-19:
> To clarify: when I say "high-Z" I mean "high-Z at the relevant frequency". i.e. an open-circuited 1m BNC cable isn't high-Z by the time you get much above DC because of the ~100pF capacitance.

That's correct. But it's not the situation that I measured. I had a low-z source-CMC-coax-CMC-high-z load setup and having the second CMC made a big difference. It's the same case here. Between the long coax and the high-z INA input the CMC will make a difference (at AC).

And regarding the filter setup: read again what I described. It's the standard wye-delta transform. It makes a difference in component tolerance sensitivity if the CM and DM impedances are different. I am pretty sure that faced with mismatch, a Y/T termination/filter does less CM to DM conversion than a delta/pi.

hartytp, 2019-11-19:
> And third, even if you want a common mode shunt, it's simply incorrect that you are constrained to the topology here. Just split the (large) differential capacitor and shunt that center tap with a smaller cap. For f_common > f_diff this should be less sensitive to component tolerances.

hmm...I haven't seen that topology used before.  From a quick think, I think that would help in the limit where:
- the resistors are tight tolerance (say 0.1% or better)
- the DM capacitance is >> than the CM capacitance
- we can ignore parasitics like the OpAmp input/diode/trace/etc capacitance (or, at least assume that they are very well matched between the two channels)

We'd need to simulate to figure out how much of a difference it would make in practice for our circuit. But, e.g. if we split the DM capacitor in two it's only about twice the size of the CM capacitors. Similarly, the total parasitics are probably only a factor of a few lower than the CM filter capacitors. So, not sure how much it would actually change things, but I agree it's another option that I hadn't thought of.

hartytp, 2019-11-19:
> That's correct. But it's not the situation that I measured. I had a low-z source-CMC-coax-CMC-high-z load setup and having the second CMC made a big difference. It's the same case here. Between the long coax and the high-z INA input the CMC will make a difference (at AC).

At what frequency? The only way I understand that is if the high-Z load setup wasn't high-Z compared with the CMC inductance.

Anyway, as I said, I agree that you can build a filter where the CMC capacitance is dominated by the parasitics, but I don't see a reason why it would be a good idea to do that in our case.

jordens, 2019-11-19:
That was a 10X 1M scope probe at <MHz IIRC. https://github.com/sinara-hw/Zotino/issues/21#issuecomment-376119235

Closed 2019-11-18.

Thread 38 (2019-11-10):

RC components

gkasprow, 2019-11-10:
For such a wide-band circuit, we cannot use standard components.
Most capacitors are not capacitors anymore at 4GHz.
That's why to have a frequency range from 1 to 4GHz we need to use either different components or connect them in parallel.
For example, 1uF,16V, 0402 from Murata (GRM033R61A105ME44)
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
Its impedance is still a few ohms but has an inductive character. It's hard to predict how it won't make resonance with parasitic capacitances.
Anyway, I will do a simulation with S models of all RF components in the path to see if we won't have any unwanted effects.

hartytp, 2019-11-10:
Can’t we use different bom options with the same pads for baseband 1MHz to 400MHz) and upconverting 400MHz to 4GHz?

gkasprow, 2019-11-10:
yes, we can.

jordens, 2019-11-10:
Also #39

I'd use different capacitors for the two variants.

dtcallcock, 2019-11-10:
Or you can use a something like an [ATC530L}(https://www.atceramics.com/UserFiles/530l.pdf), which is specifically designed for DC blocking over many octaves without these issues.  They are $0.4 ea so BOM variant option will be cheaper, but there may be some value in reducing the number of components that need switching.

jordens, 2019-11-10:
IMO it's unrealistic that those capacitors will be the right cure for a problem we haven't quantified. For the upconverter there is only one decade. Just choosing a capacitor value to place the ESR in that band will be good enough (and making sure that the capacitors are not special high-Q is pretty close to a magic (i.e. lossy) broadband capacitor). It's easier to give it a test on Mirny to see whether there are any problems with this circuit and 10 nF blocks.
The baseband version is from 1-400 MHz. Same as Urukul where we run with 10 nF throughout and see no dramatic problems. If we take the usual 100 nF here in a small package, we'll be fine.

dtcallcock, 2019-11-10:
> The baseband version is from 1-400 MHz. Same as Urukul where we run with 10 nF throughout and see no dramatic problems.

Had the amplitude vs. frequency of urukul been carefully measured by anyone yet?

jordens, 2019-11-10:
I looked at it for low frequencies (1-5 MHz) and was happy enough. IIRC we chose the corner to be around 1 MHz.

gkasprow, 2019-11-13:
Once we find some issues, I will add assembly variant with other coupling capacitor values.

hartytp, 2019-11-18:
The upconverting variant still has 1uF caps. @gkasprow please ensure that the entire RF signal path has appropriate DC block caps in both variants (cf https://github.com/sinara-hw/Phaser/issues/39).

gkasprow, 2019-11-20:
True. I will add the variant once @CannaCardo finishes the layout. In Altium one can use Variants to modify Comment field. This makes the BOM messy, so I place 2 components footprints one on top of another and assemble one of them. This is not very elegant but works.

gkasprow, 2019-11-29:
I added two sets of caps - 10nF and 1uF to support both assembly variants. The footprints are placed one on top of another.

Closed 2019-11-29.

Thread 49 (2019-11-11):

PLL LPF

hartytp, 2019-11-11:
@WeiDaZhang can you check you're happy with the current DAC PLL loop filter please?

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

hartytp, 2019-11-11:
Same for the modulator LPF

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

WeiDaZhang, 2019-11-11:
There is not much information provided about the loop filter, apart from a paragraph at top page.4
https://www.ti.com/lit/pdf/SLAA520?jktype=tech_docs
The suggestion would be:

1. Not to use the on-chip PLL, unless one has to do so.

2. Not to make the divide ratio greater than 120 when using the on-chip PLL, and therefore avoid external loop filter, unless one has to do so.

3. Use the default loop filter setting which is as the schematic is.

hartytp, 2019-11-11:
> Not to use the on-chip PLL, unless one has to do so.

Why? From the DAC data sheet, it seems pretty nice.

> Not to make the divide ratio greater than 120 when using the on-chip PLL, and therefore avoid external loop filter, unless one has to do so.

I don't follow? Why is the divider connected to using an external loop filter? In our case, the DAC clock will be 1GHz with 125MHz ref (max f_pfd is 155MHz according to data sheet).

> Use the default loop filter setting which is as the schematic is.

Okay, let's do that then...

jordens, 2019-11-11:
Because there is already an internal LF

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

But please add a 0R and a bit of space to that pin:

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

WeiDaZhang, 2019-11-11:
> > Not to use the on-chip PLL, unless one has to do so.
>
> Why? From the DAC data sheet, it seems pretty nice.]

It was said in the document, however, taking a closer look.
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
To put it in a graph we had before, it seems quite good, you are right.
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

hartytp, 2019-11-11:
Thanks @jordens @WeiDaZhang

@WeiDaZhang what about the upconverter LF? are you happy with that?

gkasprow, 2019-11-13:
>But please add a 0R (DNP) and a bit of space to that pin:

@jordens do you want to have the LF disabled by default?

jordens, 2019-11-13:
Yes. We are looking at P*M < 64 for 125 MHz and < 80 for 100 MHz reference in. 10 MHz wouldn't work anyway.

hartytp, 2019-11-18:
@WeiDaZhang please can you confirm that you're happy with the upconverter LF asap and then close this? Thanks!

WeiDaZhang, 2019-11-18:
I'm looking at it. What's the frequency PFD? I suppose it's 125MHz?

WeiDaZhang, 2019-11-18:
@hartytp

jordens, 2019-11-18:
62.5 MHz

WeiDaZhang, 2019-11-18:
This one should work. I've tried for two frequencies.
The VCO gain is not clear, I assumed (4800-2400)/5 = GVCO (MHz/V) when VCO range DIV = 1 selected. If the tuning voltage is actually 3.3V, there will be a loop bandwidth error but should remain stable.
I've allowed relatively wide loop bandwidth assuming the reference is much lower noise than the VCO even with frequency scaled.
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
C1       C2        R2    C3    R3    C4    R4
120p   3000p  330   33p  330  33p  330

hartytp, 2019-11-18:
@gkasprow can we go for @WeiDaZhang's loop filter please? Once the boards arrive, we'll test this on a phase noise meter and optimise the loop filter further.

gkasprow, 2019-11-28:
done
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

pathfinder49, 2021-03-29:
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

@hartytp What's the conclusion here? Is the idea to use the DAC PLL or bypass it?

hartytp, 2021-03-29:
> @hartytp What's the conclusion here? Is the idea to use the DAC PLL or bypass it?

Depends on the application.

Using the DAC/upconverter PLL and clocking from Kasli is generally the most convenient way of setting things up. In many cases that will be completely fine from a noise perspective.

If one needs the lowest possible noise then an external clock/LO will definitely give better results than using an internal PLL from the DAC / upconverter. NB the DAC clock is generally much less important than the upconverter (if it's being used) since, all things equal, phase noise scales like `20*log10(frequency)` so for a 3GHz carrier and 300MHz IF, one is 20dB more sensitive to the upconverter LO.

My advice would be to measure the phase noise for the upconverted RF and then decide if it's good enough for the gate. Using an external microwave source for the LO / DAC clock is there are a fallback plan if we decide it's needed.

Closed 2019-11-28.

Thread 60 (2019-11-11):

baseband amplitude

jordens, 2019-11-11:
Currently the path between the DAC and the mixer leads to some 0.5 V (25 Ohm, 20 mA) full scale current (peak single ended) by default. The mixer seems to have optimal performance (OIP3 e.g.) around 0.5 V single ended RMS, i.e. 0.71 V peak single ended and is specified up to 1 V RMS SE (1.4 V peak SE). On top there'll be some losses in the AA filter.

Proposal: use a 1:4 transformer after the AA filter to get 1 V peak SE at the mixer input. This matches the mixer input range better. That space is needed anyway for the baseband variant baluns. It gives more power at the output in both variants. There is a coarse full scale adjustment to fine tune it further. Also the eval board uses the 1:4 transformer. This does change the filter design though AFAICT.

There is `coarse_dac` for fine tuning the full scale current.

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

On the other hand the mixer datasheet talks about "VinBB = 300 mVrms single-ended sine wave in quadrature" as their favorite characterization default. So maybe 500 mV peak SE per quadrature is just right.

Also c.f. https://github.com/sinara-hw/Phaser/issues/21#issuecomment-552210181

hartytp, 2019-11-11:
> 20 mA

Isn't the DAC 30mA FS?

jordens, 2019-11-11:
20 mA typ.

hartytp, 2019-11-11:
> 20 mA typ.

IIRC there is a resistor one picks dependent on the FS current and the one we used is for 30mA. Maybe I'm wrong though...

jordens, 2019-11-11:
You'd operate it with `coarse_dac` setting it to 20 mA FS.

hartytp, 2019-11-11:
Okay, but should we change `BIASJ` then?

jordens, 2019-11-11:
No. It's the product of both.

hartytp, 2019-11-11:
okay, thanks for clarifying.

Anyway, this sounds like a good idea.

What's the 1:1 balun for?

hartytp, 2019-11-11:
@dtcallcock what's the actual min frequency you want? 1MHz or lower?

It looks like that 1:4 should be fine though

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

jordens, 2019-11-11:
I guess that two-transformer combo blocks common mode effects (e.g. the primary secondary capacitive coupling which is an intrinsic limitation in single-core baluns) a bit better. Don't know any numbers though.

jordens, 2019-11-11:
On the other hand the mixer datasheet talks about "VinBB = 300 mVrms single-ended sine wave in quadrature" as their favorite characterization default. So maybe 500 mV peak SE per quadrature is just right.

hartytp, 2019-11-11:
It does look like the mixer is designed to connect to a DAC without a balun:

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

Unless I'm missing something, DAC3283 looks very similar to 34H84 with regards to outputs...

hartytp, 2019-11-11:
No, never mind, it is a bit different

dtcallcock, 2019-11-11:
> @dtcallcock what's the actual min frequency you want? 1MHz or lower?

1 MHz should be good but it'd be nice to have at least somewhat graceful degradation down to around 300kHz if possible.

There are better and smaller 1:4 baluns for the lower frequency end (eg. [TC4-1TX+](https://www.minicircuits.com/pdfs/TC4-1TX+.pdf).  What upper frequency are you shooting for with the BB variant though?

hartytp, 2019-11-11:
> There are better and smaller 1:4 baluns for the lower frequency end (eg. TC4-1TX+. What upper frequency are you shooting for with the BB variant though?

This is just on the DAC, so I think the choice here is agnostic of which variant we're using; both need to go up to around 400MHz.

dtcallcock, 2019-11-11:
It says the TC4-1TX+ is useable to 450MHz but they don't spec it above 300MHz.  The [TC4-6TX+](https://www.minicircuits.com/pdfs/TC4-6TX+.pdf) has worse performance but the return loss holds up better above 200MHz and it's specified up to 600MHz.

jordens, 2019-11-11:
The current AA filter is already 10 dB down at 400 MHz. I wouldn't worry about the balun adding another ~3 dB.

gkasprow, 2019-11-13:
I assume we leave it as it is now.

Closed 2019-11-14.

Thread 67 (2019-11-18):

part number for TR5 missing from schematic

hartytp, 2019-11-18:

CannaCardo, 2019-11-23:
fixed

Closed 2019-11-23.

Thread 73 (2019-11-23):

Layout

gkasprow, 2019-11-23:
- [x] swap J9 and SATA connectors. Otherwise CPCIS adapter won't have access to the J9. One can swap transceivers if needed.
- [x] separate channels with L28, L36 etc . The inductors may couple and cause crosstalk
- [x] U can swap IC5 outputs

gkasprow, 2019-11-23:
- [ ] do not place vias in pads. U can switch to 0201 caps under FPGA to fit them between vias. make sure that via hole does not touch the component pad. Otherwise, it will suck the tin.
- [ ] don't even try routing on 6 layers. Move to 8 or copy the stackup from Kasli. Use the Brandner web tool for stackup creation.

gkasprow, 2019-11-23:
- [ ] move LM75 closer to the heat source: ADC and upconverter

jordens, 2019-11-23:
I think kasli is 6 layers. Would be nice to not have to go beyond kasli.

gkasprow, 2019-11-23:
Kasli is purely digital board. It has only one ground plane. Doing Phaser with only 6 layers would be tricky.

gkasprow, 2019-11-23:
Anyway, let's try to copy the DAC layout/routing from evkit and see how many layers it needs.

hartytp, 2019-11-23:
@gkasprow can you finish off the remaining schematic issues please?

hartytp, 2019-11-23:
@CannaCardo good work. Can we have the top/bottom side renders in the PDF as well please?

CannaCardo, 2019-11-23:
Renders added

hartytp, 2019-11-23:
Thanks! Do you think we can get the boards off to manufacture this week?

CannaCardo, 2019-11-23:
Most likely :)

hartytp, 2019-11-23:
Amazing, THANK YOU!

dtcallcock, 2019-11-24:
First 4 SMAs are labeled RF OUT 0-3 on silkscreen.

hartytp, 2019-11-29:
how's the layout going @CannaCardo ?

gkasprow, 2019-11-29:
I took over the design to implemented all fixes. Then I will pass it to @CannaCardo to finish. I should finish them today.

hartytp, 2019-11-29:
Aah, ok, makes sense! Thanks! (I have too many projects on the go and am trying hard to get them finished)

gkasprow, 2019-11-29:
well, at the moment I have 17 projects going. Sinara is one of them. Some of them started 10years ago and don't want to finish...

gkasprow, 2019-11-29:
@CannaCardo during finishing the routing make sure that:
- [ ] no components are placed close to the FPGA to enable assembly of the heatsink latch
- [ ] follow precisely routing of the upconverter chip Now the decoupling capacitors are far from the IC pins. The inductors or ferrite beads can be on the bottom layer or far away but the caps must follow the datasheet recommendation. Lower capacitors values must be installed closer to the IC
- [ ] All QFNs have vias in the thermal pad
- [ ] all test point, LEDs and connectors have labels which indicate their function
- [ ] all ICs, diodes, connectors, and inductors, transformers have their designator enabled. Use 1mm high font, 0.2mm stroke
- [ ] all vias in thermal pads are unmasked on the opposite side to prevent from acid pocket formation
- [ ] there are at least 2 different fiducials per side on top and bottom. Use small ones.

hartytp, 2019-11-29:
Thanks @gkasprow ! Can you post a new rc so we can sign off on the schematic please?

gkasprow, 2019-11-29:
one moment.

gkasprow, 2019-11-29:
the latest release is here
https://github.com/sinara-hw/Phaser/releases/tag/v1.0rc5
@CannaCardo you can take over the project and finish the routing.

jordens, 2019-11-30:
And put exposed polygons on the bottom layer under the two mixers like we have for the DDS on Urukul.

jordens, 2019-11-30:
And make sure that there are no tall components (that big capacitor) on the bottom that would interfere with card insertion.

jordens, 2019-11-30:
And Greg's point from above is not honored. You really need to spread out the signal paths after the DACs, especially the inductors. Even within a single diff pair the coupling between the two inductors is problematic as it reduces the filtering.

jordens, 2019-11-30:
And PI simulation. There are some really carved up polygons.

hartytp, 2019-12-01:
AFAICT all schematic review items were correctly implemented. Good work!

Layout is coming along nicely @CannaCardo! Really looking forward to getting my hands on phaser. Good work all.

hartytp, 2019-12-01:
@jordens assuming you have no objections, I suggest we freeze the schematic here.

hartytp, 2019-12-07:
@CannaCardo whats the status of this? Are we on track to get the boards to manufacture next week?

CannaCardo, 2019-12-07:
I've got almost all of the issues here done, few traces with length matching (mainly DAC area) and PI simulation are left.

hartytp, 2019-12-07:
Ace :)

So ready for review early next week sounds about right then? That would be wonderful

CannaCardo, 2019-12-07:
Yes. I've finished other projects, so there are no excuses now  :)

hartytp, 2019-12-09:
@gkasprow can you do a layout review?

dtcallcock, 2019-12-09:
Just noticed that R49 is still populated on baseband version.

gkasprow, 2019-12-09:
I finished my review

hartytp, 2019-12-09:
@gkasprow @CannaCardo a few questions:
-are you satisfied that all converters follow eval board / data sheet recommendations for the layout?
- are you happy with the digital to analog isolation and isolation of the analog from the fpga + converters?
- are the I/q channels perfectly matched? We need to avoid any asymmetry to keep the sideband suppression good
- happy with Si for high speed and analog traces?

gkasprow, 2019-12-09:
@CannaCardo, please mark remaining "ticks" above.

hartytp, 2019-12-09:
- happy with layout and routing of the rf signals to give good si and minimise parasitical in filters etc

gkasprow, 2019-12-09:
Once all the issues I posted are addressed, I would be happy.
In the end, I will make a few GND cutouts to limit the spreading of EMI from DC/DC to RF part.

hartytp, 2019-12-09:
Copying the only unchecked issue from above:

- [ ] follow precisely routing of the upconverter chip Now the decoupling capacitors are far from the IC pins. The inductors or ferrite beads can be on the bottom layer or far away but the caps must follow the datasheet recommendation. Lower capacitors values must be installed closer to the IC

hartytp, 2019-12-09:
Anyway, very excited that we're now so close to getting this off. Just Booster after this...

hartytp, 2019-12-09:
One really nit picky thing that you may feel isn't worth it...
- [ ] on stabilier all the power TPs and LEDs are in a row with a couple of GND pads there as well. That made spotting mistakes and checking supplies really quick (don't need to search for them and you can really see if one supply isn't coming on properly). If it's not too much work we should to that here as well

CannaCardo, 2019-12-11:
>  on stabilier all the power TPs and LEDs are in a row with a couple of GND pads there as well.

I've added GND pads visibly near the testpoints, should be easy to find

hartytp, 2019-12-11:
What was nice on Stabilizer was that all TPs and LEDs were in a row, so one could check all power rails by eye really quickly without having to search over the board. That's much nicer than having them scattered over the board. But, I understand if it's too much work to do that now.

CannaCardo, 2019-12-11:
I'll keep that in mind with future boards ;)

hartytp, 2019-12-13:
@CannaCardo how's this going? Any chance of getting another RC today so we can do our final reviews over the weekend and send off to production on Monday?

CannaCardo, 2019-12-13:
I added the next RC, still without PI/ copper balancing as I don't have access to a hyperlynx license at the moment.

gkasprow, 2019-12-13:
I will simulate it with Ansys PDN or CST PDN over the weekend. I have a private license for both.

hartytp, 2019-12-13:
@CannaCardo awesome! Did you folow the upconverter reference design layout? If so, I think all issues here are resolved and we can close this. Well done.

CannaCardo, 2019-12-13:
Yes, the image on the schematic is upside-down compared to the PCB

hartytp, 2019-12-13:
Great, thanks!

gkasprow, 2019-12-13:
yes, layout is OK, but I still don't think the ref design is done correctly:)

hartytp, 2019-12-13:
@gkasprow are you happy with the layout? In particular the usual things like:
- loop area in high-frequency/low-noise (LF etc) signals?
- position of decoupling capacitors
- IQ and channel-channel matching/symmetry
- noise sources (SMPSs/digital traces)
- controlled impedances

etc? If so let's close this and send to manufacture after PI

hartytp, 2019-12-16:
@gkasprow thanks for doing all that!

It looks like most open issues can be closed now. What’s left to do? Can you post a final rc once all changes are complete so we can sign off?

Closed 2019-12-17.

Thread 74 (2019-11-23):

Mmcx ref clock input location

jordens, 2019-11-23:
Should be as far back as possible. And the cable should not interfere with the eem ribbons, the sata cables or the J9 high speed connector and its counterpart.
The location of the mmcx on urukul and mirny near the front panel is not very good.

Jtag on the other hand can be pretty much anywhere. No need for it to be in the back.

Probably the samtec gigabit hermaphroditic connector should be located where the jtag connector is now. But it should be in a location where its corresponding connector on the cPCI-S adapter does not interfere with anything on any of the existing other EEM module (e.g. should not interfere with the +-15 V modules on Zotino/Fastino/Sampler, @gkasprow should check this).

CannaCardo, 2019-11-25:
Would here be ok, considering the CPCIS adapter?
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

jordens, 2019-11-26:
The current cPCI-S design has a specific MMCX clock output that derives it from a diff pair on the cPCI backplane. But it doesn't have that gigabit serial connector yet.
I think for c-PCI-S the clock should be placed on the gigabit connector and there should be no MMCX jumper. To do that (a) place MMCX in just above the right EEM, (b) the gigabit connector above the left EEM (or between the EEMs if that fits), (c) add jumper capacitors to switch the clock between the balun and a pair on the gigabit connector. @gkasprow does this make sense?

gkasprow, 2019-11-28:
yes. done.

gkasprow, 2019-11-28:
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

gkasprow, 2019-11-29:
btw, recent CERN DI/OT board based on 500$ ZU7 SoC has also gigabit line per CPCIS slot + 15 LVDS + low jitter clock. WIth one assembly option the user can decide if one needs 16-th LVDS or gigabit link.
The project is here https://ohwr.org/project/diot/wikis/home
In a few days I will update schematics.

gkasprow, 2019-11-29:
the Open source CPCIS backplane is already designed (in Kicad) and goes for production.
Low-cost 400W PSU is in the design phase.

Closed 2019-11-28.

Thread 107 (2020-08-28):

fan pwm

jordens, 2020-08-28:
I can't seem to bring the gate low enough to turn the fan off. This is with a 1 (or 0.25) MHz PWM and any duty cycle.
@gkasprow how is this supposed to work?

gkasprow, 2020-08-28:
the idea is that you cannot turn it off with logic level. You must use PWM.
However, the BSH103 has a very low Vth. Originally BSS138 was used, then it was replaced probably to unify the BOM.
If the circuit does not work with very low duty cycles, it may be caused by very low Vth of this particular T20. You can try to replace it with BSS138.
The circuit does just a DC-restoration, that makes sure the logic pattern on the FPGA appears on T20 unchanged, only shifted up by roughly 0.2V (Schottky diode Vf). When FPGA is not toggling, after the RC time constant, T20 starts conducting.
You can also short C159 if you don't care about such protection.

gkasprow, 2020-08-28:
You can also replace T20 with BSS138

jordens, 2020-08-28:
That's what I thought. The minimum gate voltage is above 0.7 V already at 0.5 duty cycle and increases below that.
Then we'll either have to change the FET or RC to make it work.

gkasprow, 2021-03-11:
changed to BSS138

Closed 2021-03-11.

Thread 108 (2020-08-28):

N11V5 LED current

hartytp, 2020-08-28:
10mA feels a little sadistic. I assume this is a BOM error?

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

gkasprow, 2020-09-24:
yes, ~9mA is too much. should be less than 1mA.

I would also move all LEDS in one place like in Kasli

Closed 2021-03-11.

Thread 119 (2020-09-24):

check reconstruction filter

jordens, 2020-09-24:
For the upconverter variant we should closely follow the relevant eval boards (important for noise floor due to mixing products, bandwidth, flatness, proper matching, proper output power).

* Consider (or exclude) going DC coupled
* Consider the transformer network
* Double check and follow the guidelines and design procedure from the datasheets.

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
and others from [slua647a](https://www.ti.com/lit/ug/slua647a/slua647a.pdf)

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
from [TSW30H84EWM](https://www.ti.com/tool/TSW30H84EVM)

jordens, 2020-09-24:
https://github.com/sinara-hw/Phaser/issues/4#issuecomment-551014195

I think the approach may be good, we should just be sure what we want.

gkasprow, 2021-03-11:
@hartytp anything to do here?

hartytp, 2021-03-12:
I'm happy with the current filter. AFAICT we followed a sensible process to come up with the filter we chose so unless there is a specific issue with it I'm not aware of a need for change (but maybe @jordens has further thoughts?). We don't have a tight spec for what we're trying to achieve with this, which means that we can't optimize the solution too far.

jordens, 2021-03-12:
To close this, the current performance should be measured (power and frequency characteristics, crosstalk, IMD2 and IMD3 due to impedance errors). If that's ok, this can stay. IMO it would be better if someone does this thoroughly instead of later everybody for themselves in just their frequency window of interest.
AFAIK we don't even know the performance in a single window yet and whether it matches the design. I'd hesitate closing this.

jordens, 2021-03-12:
Yes. It's not a release blocker.

pathfinder49, 2021-04-13:
I've measured the filter attenuation for a range of DAC frequencies. The measurement was made by measuring the single ended power of a DAC output before and after the filter. I used the Keysight N2795A 1GHz, 1pF probe to reduce probe loading.

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

pathfinder49, 2021-04-13:
Note: The DAC output amplitude changes appreciably with frequency. The plot above does not represent the phaser output amplitude change with frequency.

hartytp, 2021-04-13:
Assuming I've followed this correctly, the comparison is with https://github.com/sinara-hw/Phaser/issues/4#issuecomment-551014195 This data looks really quite different to the simulation, so we should check that we have got this right...

pathfinder49, 2021-04-13:
@hartytp It's tricky to read of the plot you linked accurately. However, aside from the ~30 dB offset, my measurement looks consistent with the 10-300 MHz range from the simulation.

hartytp, 2021-04-13:
maybe you're right and I'm misreading it (I wouldn't worry about the 30dB offset until we've thought about units etc).

Can you compare to the [SPICE model](https://github.com/sinara-hw/Phaser/tree/master/Calc_SIM)

pathfinder49, 2021-04-13:
Seems like the Spice model is only for for the voltage regulator. The filter simulation requires Tina. I'll take a look at the trial later (unless @gkasprow can easily make a plot for comparison)

gkasprow, 2021-04-13:
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

gkasprow, 2021-04-13:
In the simulation, the peaking is 1.08dB

pathfinder49, 2021-04-13:
For context, I've measured the net power-frequency dependence for Phaser upconverter. There seems to be more significant variation than we have in the filter.

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
DUC in blue, NCO in orange

The DUC drop-off at higher frequencies is expected.

jordens, 2022-09-12:
If we could improve the DAC AA filter (relevant for both variants) and the DAC-Mixer matching (Upvonverter), that would be really useful. Right now with the AA filter doing -3 dB already before 300 MHz and the overall match having 6 dB ripple over 250 MHz, it's certainly below what's possible.
Something like -0.2 dB @ 350 MHz, -35 dB at 650 MHz should be possible. And the impedances thoroughly reviewed.

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
https://rf-tools.com/lc-filter/

jordens, 2022-09-12:
Alternatively LTCC filters, https://www.minicircuits.com/pdfs/LFCN-320.pdf (100 Ohm as a balanced pair)

gkasprow, 2022-09-13:
@jordens It didn't go for production yet so we will update it.
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

gkasprow, 2022-09-13:
it fits
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

jordens, 2022-09-13:
For baseband, if we do 200 R balanced, then the traces should also have that impedance up to the balun.

If possible, I'd separate the P and L inductors a bit to minimize coupling.

Interestingly, on the eval board they put the source termination after the AA filter. Not sure if that's worth it.
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

In the upconverter variant we need to also then make the load impedance 200 R after the filter. By using a 2:1 balbal and the datasheet 100 R termination at the mixer input (TC2-1T+ in the footprint of the baseband 4:1 balun).

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

Alternatively a 200R termination and no balbal. But I'd prefer the balbal and 100 R termination.

gkasprow, 2022-09-13:
@jordens we cannot change the trace impedance between assembly options.
 but traces are so short that it doesn't really matter.
For the moment in upconverter variant we use 50Ohm DAC load and 2x60R4 series resistors at the output of the filter which together with 91Ohm load make more or less 200Ohm

gkasprow, 2022-09-13:
200R impedance is impossible with current PCB stackup. Even two 80um traces separated by 1mm would give 130Ohm

jordens, 2022-09-13:
It was specifically the Upconverter variant that had large ripples (https://github.com/sinara-hw/Phaser/issues/119#issuecomment-818931327) much larger than the simulation/design (https://github.com/sinara-hw/Phaser/issues/4#issuecomment-551014195).
Isn't the match between the 50 R at the DAC and the 200 R at the TRF a bit bad? Both in simulation and in practice?
Your original plan from the datasheet (https://github.com/sinara-hw/Phaser/issues/4#issuecomment-550489607) had 250 R on both ends.

jordens, 2022-09-13:
Ok. Then let's stick with 100 R balanced trace impedance throughout. I'm also not too worried about that.

gkasprow, 2022-09-13:
what we can do is to use 100R DAC loads in both assembly variants

jordens, 2022-09-13:
@pathfinder49 @FabianSchwartau what do you think?

gkasprow, 2022-09-13:
the XFMR_MINI-CIRCUITS TC2-72T+ has same footprint

gkasprow, 2022-09-13:
the schematic for upconverter variant would be as follows. I added caps at the output
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

jordens, 2022-09-13:
The 100 R at the DAC needs to go (everything should be the same up to the balbal. Otherwise looks good. Also TC2-72T+ in favor of TC2-1T+ for better balance and flatter response.
And in both cases there can't be a series C in the filter (remove C135 C138) as the DC current path to the center tap needs to be there.

gkasprow, 2022-09-13:
fixed

jordens, 2022-09-13:
@gkasprow As mentioned above, I'd prefer the straight 100 R differential termination as close as possible to the modulator as in the eval board. Can we 0R those inductors?

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

gkasprow, 2022-09-14:
OK

pathfinder49, 2022-09-14:
> @pathfinder49 @FabianSchwartau what do you think?

I haven't thought too much about different filter options. However, I'm generally in favour of anything increasing Phaser output power. The power is painfully low and in some scenarios the signal to noise ratio was limiting for me with either variant.

jordens, 2022-09-14:
@pathfinder49 For that to be the case it would need to be attenuated so low that the DAC(+Upconverter) noise gets near the thermal floor, something like -30 dBm output for typical frequencies. It would surprise me if that's the case (it wasn't in my tests). Could you check where the power is lost, what should be achieved, and propose fixes?

gkasprow, 2022-09-14:
We can think of adding high linearity power stage similar to Booster HL but lower power.
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
hartytp, 2022-09-14:
Do we really get -20dBm out of the phaser upconverter? My understanding is that we expect ~0dBm out of the DAC and a few dB of conversion loss in the upconverter so something like -6dBm including filters. Are my expectations wrong or is there a bug in the design?

pathfinder49, 2022-09-14:
> Your final power and the overall amplification have nothing to do with the SNR as long as yo aren't limited by the thermal noise floor. Did you distinguish the noise floor hitting thermal floor from the effect of close-to-LO noise (1/f etc)? This is the chance to look at it and figure out whether what you claim is compatible with a nominal -3 dB mixer gain, the noise of the upconverter and the DAC, and the carrier power vs thermal.

I distinguished the effects by measuring coherence time response to placing attenuators at diffrerent points in the microwave signal chain. When not attenuated or switched the Phaser upconverter output noise dominates over this effect. However, it is straightforward to include a TTL switch in the unconverted phaser output (and I did).

> Do we really get -20dBm out of the phaser upconverter? My understanding is that we expect ~0dBm out of the DAC and a few dB of conversion loss in the upconverter so something like -6dBm including filters. Are my expectations wrong or is there a bug in the design?

The absolute maximum I can get around 3 GHz [is -10 dBm](https://github.com/sinara-hw/Phaser/issues/130#issuecomment-817925371) with a breakdown [here](https://github.com/sinara-hw/Phaser/issues/130#issuecomment-818631631).

By the time you're [not sitting on the filter resonance peak](https://github.com/sinara-hw/Phaser/issues/130#issuecomment-818635081), avoid digital clipping, and use two tones you lose another 10 dB. So in realistic use cases the available power per tone is -20 dBm (plus cable losses).

jordens, 2022-09-15:
Still unclear what other settings you had there. I [asked](https://github.com/sinara-hw/Phaser/issues/130#issuecomment-817988851) for that info but there was no response. Please review the filter, identify why it doesn't meet the goals, and propose solutions if you are really interested in this. E.g. check whether the proposed would work, or even a 4:1 balbal with a 200 R termination at the mixer as proposed. Doing a quick test on hardware is also helpful.

Also it's not clear to me why an external mixer with the baseband variant would help with power over the upconverter. It uses the exact same reconstruction filter with the same loss and the mixer will have similar gain. Also with the I and Q outputs now being significantly different circuits matching group delays, amplitudes, phases, and DC offsets would be significantly more annoying, more so if this is supposed to work over a non-trivial frequency range.

One thing that may be doable is adding an RF switch to kill the output, assuming we can find a good broad band one.
But then again it's easy to just add 32 dB from the attenuator while not doing gates. That's much better broad band noise suppression than the 5 dB you are hunting.
Also if the DAC is outputting DC, I'm pretty sure broadband noise at the upconverter input will be below the datasheet value of the DAC output for non-DC. Another easy knob to use.

pathfinder49, 2022-09-15:
> Please review the filter, identify why it doesn't meet the goals, and propose solutions if you are really interested in this. E.g. check whether the proposed would work, or even a 4:1 balbal with a 200 R termination at the mixer as proposed. Doing a quick test on hardware is also helpful.

I currently have no bandwidth for any further work on Phaser.

> Also it's not clear to me why an external mixer with the baseband variant would help with power over the upconverter.

Maybe take a look at where the power losses occur?

> That's much better broad band noise suppression than the 5 dB you are hunting

I'm not hunting anything. You asked me for my thoughts, which I have given. I have what I need and you are welcome to do any further characterisation you need.

jordens, 2022-09-15:
Good luck with that attitude.

Closed 2022-09-13.

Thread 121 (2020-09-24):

replace TRN 3-1222

hartytp, 2020-09-24:
phaser burns off a lot of power. We should be careful not to be wasteful and let the usage creep up unneccecarily.

The TRN 3-1222 uses 480mW (40mA) quiescent, which is a lot bearing in mind that we only need ~20mA from each rail.

Replacing this with the 1W converter in the same family would halve the quiescent current, which would help a lot.

gkasprow, 2020-09-24:
True. We don't need that much.

gkasprow, 2021-03-11:
I will replace them with dedicated buck and inverting synchronous converters

hartytp, 2021-03-11:
:+1:

gkasprow, 2021-03-11:
Not that easy. the negative sync converters work up to -5.5V.
And we need to create 12V out of input voltage which can be less than 12V.
We have to use SEPIC converter, for example LT8582 which delivers +/- 12V. We can also go for LTM8049.

gkasprow, 2021-03-11:
But it is overkill.
Let's go for [NMJ1212SC](https://datasheet.octopart.com/NMJ1212SC-Murata-Power-Solutions-datasheet-6387223.pdf). it consumes 250mW of quiescent power.

gkasprow, 2021-03-11:
we can also go for [MTU1D1212MC](https://www.murata.com/products/productdata/8807030456350/kdc-mtu1.pdf?1612841424000), it has higher efficiency and lower ripples, but has a non-standard footprint.
[NMV1212SC](https://datasheet.octopart.com/NMV1212SC-Murata-Power-Solutions-datasheet-6396052.pdf) has standard pinout and higher efficiency. The same with TRN 1-1222 which has better output stability.

gkasprow, 2021-03-11:
Let's use TRN 1-1222 then

Closed 2021-03-11.

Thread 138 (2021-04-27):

TRF LO output level varies when loading second output

Jacky2k, 2021-04-27:
Hi everyone,
I noticed a strange behaviour of the LO output levels of the TRF: When I connect a 50 Ohm load to the LO OUT N of the first TRF (J14B), the amplitude of the internal LO connection (connected to LO OUT P) varies significantly (something like 15 dB!). Interestingly the amplitude of P is higher, when the N output is loaded.
I am not 100% sure where this is coming from. It may be, that the differential output does not like being loaded differently, I could not find any information in the datasheet about this.
I have to mention, that I replaced the 10 dB attenuator with a 0 Ohm resistor, according to the discussion in https://github.com/sinara-hw/Phaser/issues/136. I will change this back shortly, and see if that makes any difference.
Any idea why the board is behaving like this?

gkasprow, 2021-04-27:
are you using AC or DC connection? I mean before or after the coupling cap ?

Jacky2k, 2021-04-27:
I measured at the input of the the 10 dB attenuator (or my 0 Ohm resistor).
Putting the attenuator back in place reduces the effect to ~6 dB, but that is still a problem.
I noticed, that TI put a 100 Ohm resistor between N and P in the eval board, that is the only difference I can see.

Jacky2k, 2021-04-27:
I am an idiot and I am sorry.
I had a wrong power value set in my RF generator all the time, the LO outputs work as expected.
Once everything is setup properly I measure roughly -2 dBm under all circumstances.

Closed 2021-04-27.

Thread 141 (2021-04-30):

Phaser 1.0: Reference clock leakage into RF outputs

pathfinder49, 2021-04-30:
There is appreciable leakage of reference clock harmonics into the RF outputs. There leakage is found wheth the mmcx or SMA clock are used and in both the Baseband and Upconverter variants.

# Overview
Clock leakage at 125 MHz is quite low at -100 dB. However, the leakage increases at higher frequencies. At the 3.125 GHz harmonic, the attenuation of the external clock to the outputs is only -40 dB.

Clocking Phaser with a ~2.3 dBm square wave, results in approximately -75 dBm output spurs at 3.125 GHz. Using The Kasli-clock via MMCX results in a -85 dBm spur in channel 1. For context the upconverter maximum output power in much of its f_lo +- 500 MHz range is around -20 to -30 dBm. These clock spurs are only 45 dB below this signal power and are close to the upconverter signal frequencies.

This is not particularly concerning for the baseband variant as these high frequency spurs can be filtered out.

# Details
The 3.125 GHz output-spur amplitudes on phaser-upconverter depend on whether the MMCX or front-panel inputs are used.

If the front panel input is used, the spur amplitudes do not depend on whether phaser is power. These can be observed by simply connecting a phaser board to a clock input and a spectrum analyser to the chosen output. The coupling to ch0 and ch1 is -47 and -37 dB respectively. These do not change appreciably when phaser is powered.

The MMCX-input leakage on an un-powered phaser is much less than that of the SMA input (roughly -70 dB). When powering the board (and selecting the MMCX clock) this increases to roughly -50 dB for both output channels.

# Notes
- The front-pannel clock is associated with the largest coupling by roughly 20 dB.
- To me, the MMCX behaviour suggests that the clock distribution on phaser is responsible for coupling around -50 dB.
- The issue can be worked around by passing the clock through a low-pass filter before feedig it to phaser.

gkasprow, 2021-04-30:
This can be caused by additional RC impedances between the SMA  ground and board GND.
Do we need these "floating connector ground" features? It may cause more harm than good.
You can try to connect the SA between board GND, and the clock SMA ground?
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

hartytp, 2021-04-30:
> Do we need these "floating connector ground" features? It may cause more harm than good.

If they're causing issues, I'd be very happy to scrap them. We started doing this a long time ago and should probably re-evaluate whether they're really the right thing to do

pathfinder49, 2021-04-30:
Another thought: When looking through the schematics, I noticed the front panel clock changes ground reference layer without any nearby ground vias. IIRC for EMI differential pairs couple quite similarly to individual traces (an example is next to TR2 in the picture above). This may cause return currents to spread out.

I don't have access to Altium right now, so could provide images later.

pathfinder49, 2021-04-30:
> You can try to connect the SA between board GND, and the clock SMA ground?

I'd rather keep re-working to a minimum. Replacements seem to be hard to come by :(

gkasprow, 2021-04-30:
I mean to connect SA ( Spectrum Analyzer) and measure the SMA ground bouncing

gkasprow, 2021-05-05:
I removed the SMA "AC isolation" components. That should help.

gkasprow, 2021-05-05:
@pathfinder49 can you make to clock input floating? To do so, remove C37, R14, and R81. That would reduce the ground loop and possibly lower the leakage.

gkasprow, 2021-05-05:
Actually, you need to remove only R81, other components are DNP already

jordens, 2022-09-15:
No bandwidth and interest by author to provide input. Closing.

Closed 2022-09-15.

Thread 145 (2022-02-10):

IC35 P1V8A supply is hot

jbqubit, 2022-02-10:
IC35 is power for P1V8A which supplies Si53340-B-GM (clock fanout). It is > 60 C (without fan). This seems anomalously hot. @gkasprow [noted](https://github.com/sinara-hw/Phaser/issues/116#issuecomment-698469813) that the current is nominal.

gkasprow, 2022-02-10:
@jbqubit how are you cooling the board? Do you measure temperature with PCB lying on the table or, in the rack with airflow?

jbqubit, 2022-02-10:
The board is lying on a table with no rack airflow. This will be better with forced air but wanted to bring this to your attention in case there's something odd going on.

gkasprow, 2022-02-10:
the clock fanout consumes ~140mA and has 3.3-1.8V =1.5V dropout. It dissipates 0.2W of power. Should not be hot at all!
I'll look at it.

gkasprow, 2022-09-09:
I didn't find anything suspicious. I added copper area around pins to lower Rth

gkasprow, 2022-09-09:
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

Closed 2022-09-09.

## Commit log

2019-09-17 initial schmatics and placement
    [DIO_MCX.PrjPCB, DIO_MCX.schdoc, DIO_MCX_Supply.SchDoc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]
2019-09-21 initial schematics
    [Digital_Attenuator_Amp.SchDoc, Mixer_coupler.SchDoc, PWR_Det.SchDoc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]
2019-09-29 sch update
    [Digital_Attenuator_Amp.SchDoc, Mixer_coupler.SchDoc, Quad_DDS.SchDoc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]
2019-11-23 v1.0rc4
    Rough layout done
    [ADC_2CH.SchDoc, Attenuator.SchDoc, CLK_INPUT.SchDoc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]
2019-11-28 initial routing
    [ADC_2CH.SchDoc, CLK_INPUT.SchDoc, DAC.SchDoc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]
2019-12-09 v1.0rc6
    No PI simulation yet
    No copper balancing yet (after PI)
    [ADC_2CH.SchDoc, CLK_INPUT.SchDoc, DAC.SchDoc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]
2019-12-16 fixed PI issues
    [Attenuator.SchDoc, DAC_SUPPLY.SchDoc, FPGA_SDRAM.SchDoc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]
2022-09-14 v1.1.2 rc3 added 100R termination to the upconverter
    [Phaser.PrjPCB, Upconversion.SchDoc]
